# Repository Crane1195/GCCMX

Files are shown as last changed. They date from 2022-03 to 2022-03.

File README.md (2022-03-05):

# GCCMX
A digital controller PCB/chassis design.

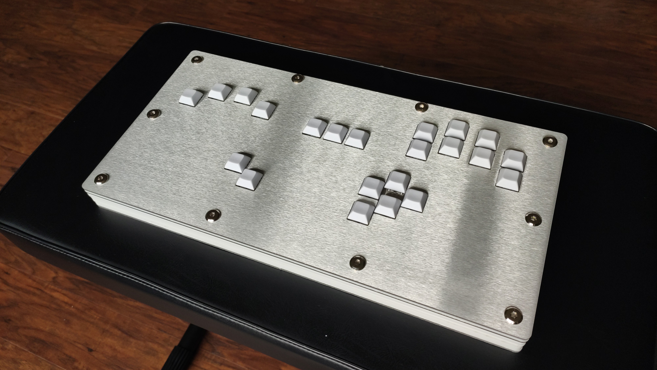
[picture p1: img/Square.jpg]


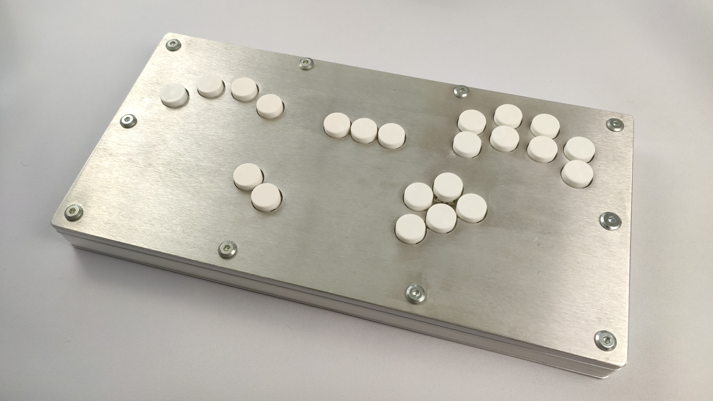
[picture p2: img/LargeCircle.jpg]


The PCB is originally designed to allow mounting a Model S and a Brook board, but you can also just solder wires to the through holes. The pin holes are labeled on the silk screen of the board.

## License
This project is licenced under the GNU GPL Version 3. [See the included LICENSE file for details](LICENSE).

## Support my work
I set up a donation link for people who appreciate my work and wish to donate. Donations are greatly appreciated, but are far from necessary:

https://www.paypal.com/donate/?hosted_button_id=NFDEML5FKR8N8

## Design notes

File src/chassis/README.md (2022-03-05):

## Switch Cover Layers

If you want to use Frame1/Gamerfinger sized keycaps (20.64mm), use a ~9mm GFCover layer.

If you want to use normal square keycaps, use a ~6mm SquareCover layer.

If you want to use small circular (sometimes called typewriter style) keycaps, you can either use a ~9mm GFCover layer to have the ability to swap to those later, or a ~6mm GFCover layer with a ~3mm SmallCover layer on top.

## Switch Plate

Get a ~1.5mm SwitchPlate layer in aluminum/steel/brass.

## Wall Layers

If you are using a GCCMX switch PCB + Model S logic PCB, use a 9mm GCCMXCover, and a 12mm ModelSCover.

If you want to use any other internals, with a Neutrik form factor feedthrough, get a 24mm GenericWallLayer.

If you want to use some other feedthrough, you can modify the GenericWallLayer file's cutout and order whatever thickenss panel fits your needs.

## Bottom Layer

Get whatever thickness Bottom panel that would be sturdy. I have done 3mm acrylic layers, and I imagine 1.5mm metal layers would be fine too.

## Model S USBC Cover

If you are using a Model S and have access to a 3D printer, this STL can be printed to cover the USBC cutout.

## Recommended US Laser Cutters

https://sendcutsend.com/ - Excellent metal cutting prices, free and fast production/shipping. Also has other materials nowadays. ACM is a really interesting/cheap material.

https://www.ponoko.com/ - Tons of material options, solid pricing, good bulk discounts, but they take quite a while to arrive.

https://www.pololu.com/product/749 - Fewer options than Ponoko, but still quite a lot. Similar pricing to Ponoko, but no bulk AFAIK. Ships faster than Ponoko.

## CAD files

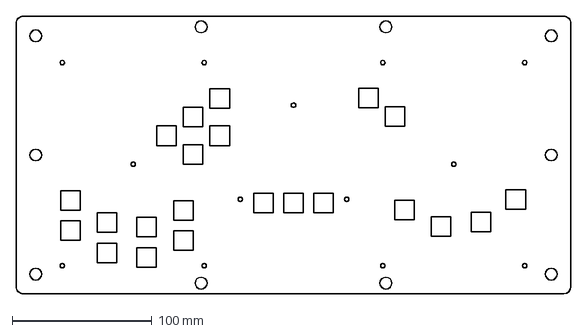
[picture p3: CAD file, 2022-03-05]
src/chassis/3_SwitchPlate.dxf
397.2 x 198.6 mm

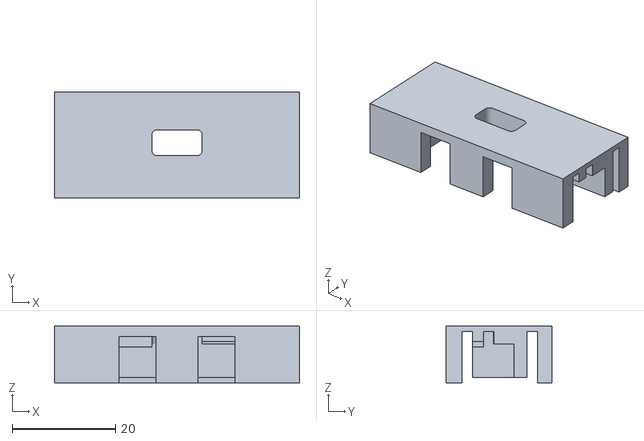
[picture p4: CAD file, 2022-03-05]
src/chassis/ModelS_USBC_Cover.stl
47.5 x 20.5 x 11.0

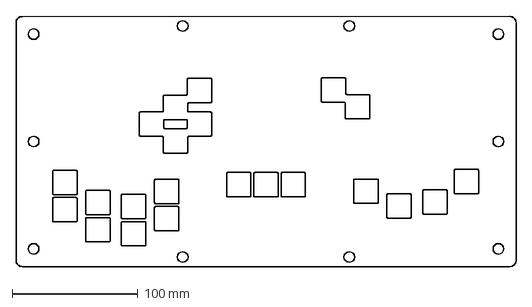
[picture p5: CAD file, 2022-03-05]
src/chassis/1_SquareCover.dxf
397.2 x 198.6 mm

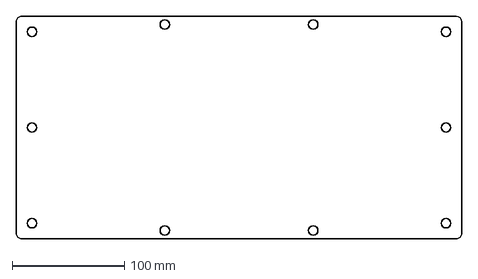
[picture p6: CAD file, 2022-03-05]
src/chassis/6_Bottom.dxf
397.2 x 198.6 mm

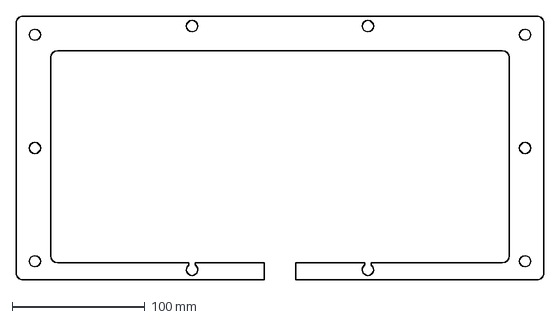
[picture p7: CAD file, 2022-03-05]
src/chassis/4+5_GenericWallLayer.dxf
397.2 x 198.6 mm

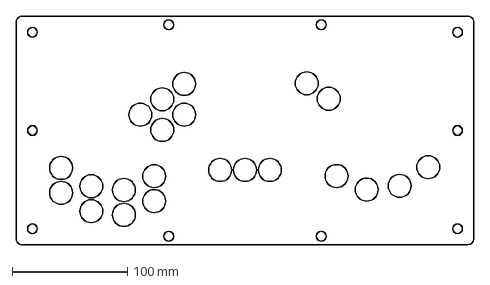
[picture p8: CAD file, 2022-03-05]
src/chassis/1_SmallCover.dxf
397.2 x 198.6 mm

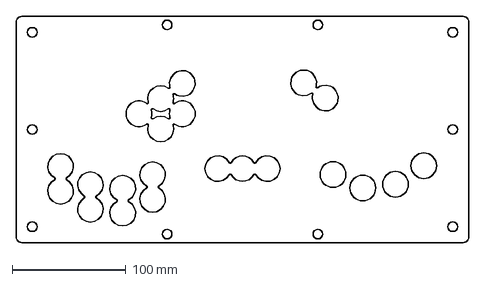
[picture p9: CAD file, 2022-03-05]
src/chassis/1_GFCover.dxf
397.2 x 198.6 mm

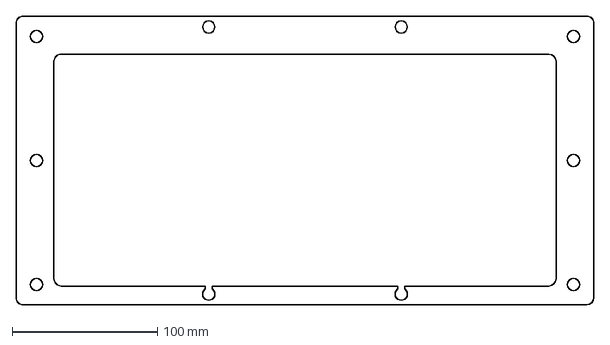
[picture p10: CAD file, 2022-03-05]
src/chassis/4_GCCMXCover.dxf
397.2 x 198.6 mm

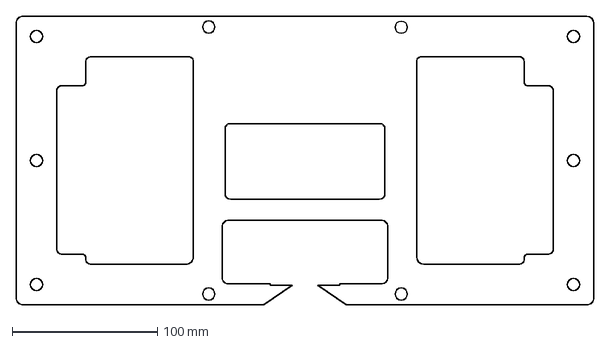
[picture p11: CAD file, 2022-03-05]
src/chassis/5_ModelSCover.dxf
397.2 x 198.6 mm

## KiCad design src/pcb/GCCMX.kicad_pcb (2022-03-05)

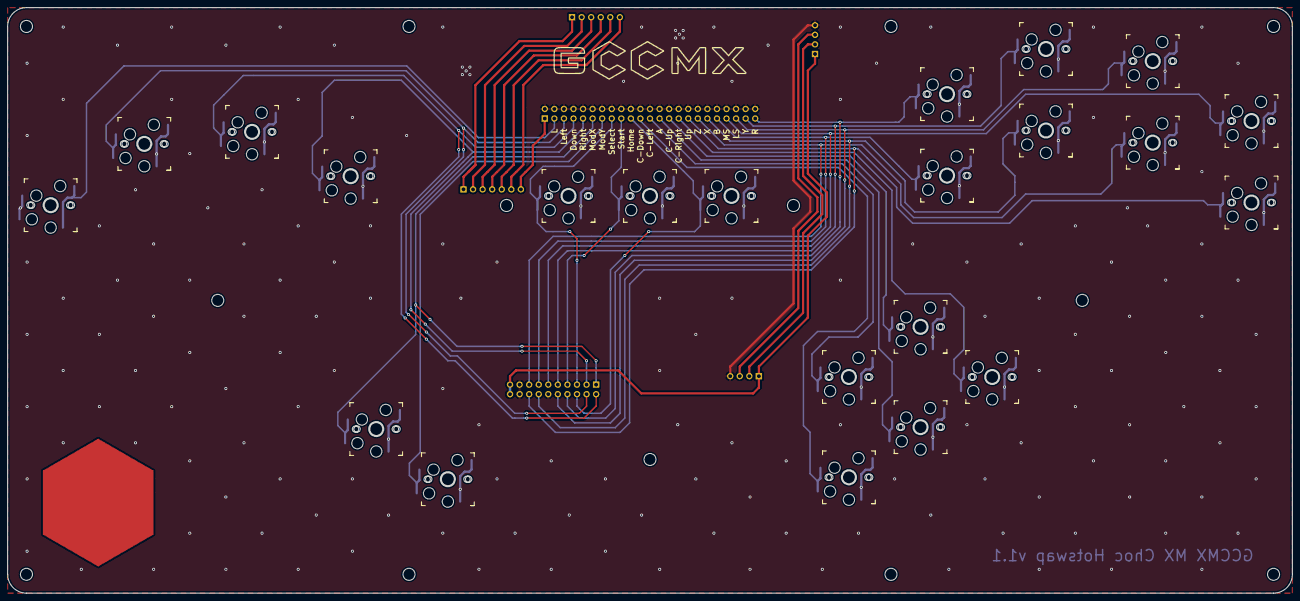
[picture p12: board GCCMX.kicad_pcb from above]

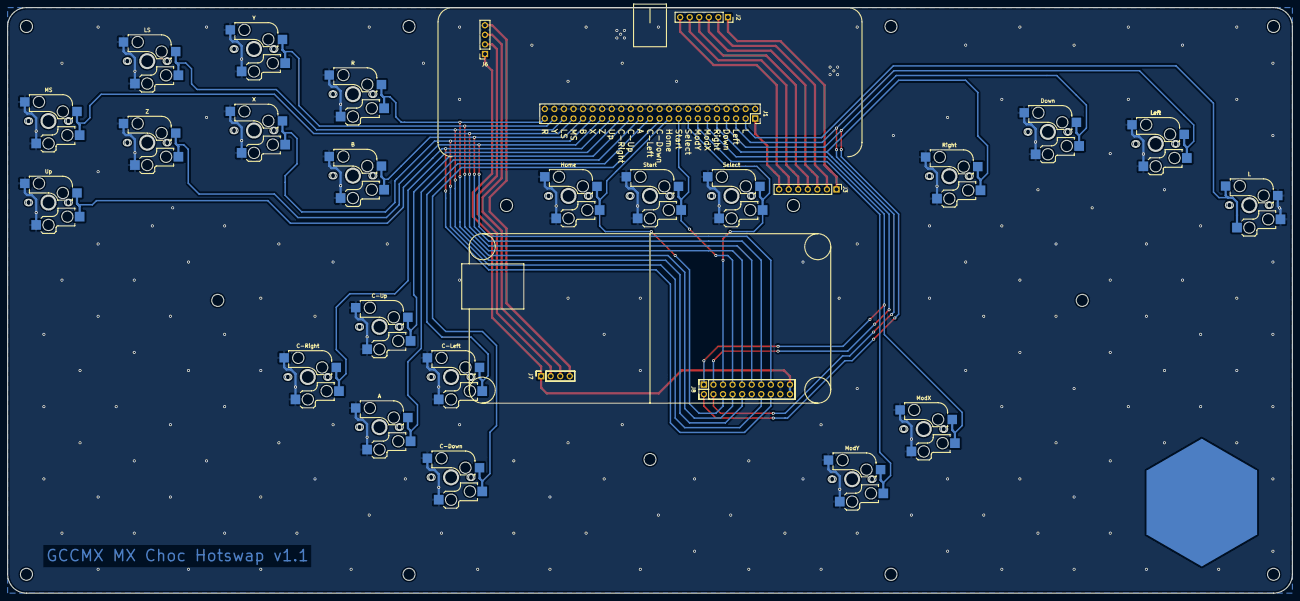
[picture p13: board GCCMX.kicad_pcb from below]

Board: 2 copper layers, 341.2 x 155.5 mm, 28 parts (6 on the bottom side), 33 nets.

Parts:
A: SW_SPST; Kailh_socket_MX+PG1350
B: SW_SPST; Kailh_socket_MX+PG1350
C-Down: SW_SPST; Kailh_socket_MX+PG1350
C-Left: SW_SPST; Kailh_socket_MX+PG1350
C-Right: SW_SPST; Kailh_socket_MX+PG1350
C-Up: SW_SPST; Kailh_socket_MX+PG1350
Down: SW_SPST; Kailh_socket_MX+PG1350
Home: SW_SPST; Kailh_socket_MX+PG1350
J1: Inputs Female; PinSocket_2x23_P2.54mm_Vertical
J2: Debug In; PinSocket_1x06_P2.54mm_Vertical
J3: Debug Out; PinHeader_1x07_P2.54mm_Vertical
J6: USB-IN; PinSocket_1x04_P2.54mm_Vertical
J7: USB-OUT; PinSocket_1x04_P2.54mm_Vertical
J8: Brook Out; PinSocket_2x10_P2.54mm_Vertical
L: SW_SPST; Kailh_socket_MX+PG1350
LS: SW_SPST; Kailh_socket_MX+PG1350
Left: SW_SPST; Kailh_socket_MX+PG1350
MS: SW_SPST; Kailh_socket_MX+PG1350
ModX: SW_SPST; Kailh_socket_MX+PG1350
ModY: SW_SPST; Kailh_socket_MX+PG1350
R: SW_SPST; Kailh_socket_MX+PG1350
Right: SW_SPST; Kailh_socket_MX+PG1350
Select: SW_SPST; Kailh_socket_MX+PG1350
Start: SW_SPST; Kailh_socket_MX+PG1350
Up: SW_SPST; Kailh_socket_MX+PG1350
X: SW_SPST; Kailh_socket_MX+PG1350
Y: SW_SPST; Kailh_socket_MX+PG1350
Z: SW_SPST; Kailh_socket_MX+PG1350

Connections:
/A: A.2, J1.25
/B: B.2, J1.37, J8.13
/C-D: C-Down.2, J1.21
/C-L: C-Left.2, J1.23
/C-R: C-Right.2, J1.29
/C-U: C-Up.2, J1.27
/Down: Down.2, J1.7, J8.2
/Home: Home.2, J1.19, J8.6
/L: J1.3, L.1
/LS: J1.41, J8.10, LS.2
/Left: J1.5, J8.4, Left.2
/MS: J1.39, J8.11, MS.2
/ModX: J1.11, J8.1, ModX.2
/ModY: J1.13, ModY.2
/R: J1.45, J8.8, R.2
/Right: J1.9, J8.3, Right.2
/Select: J1.15, J8.5, Select.2
/Start: J1.17, J8.7, Start.2
/TXLED: J1.1, J3.7
/Up: J1.31, J8.16, Up.2
/X: J1.35, J8.14, X.2
/Y: J1.43, J8.9, Y.2
/Z: J1.33, J8.15, Z.2
GND: A.1, B.1, C-Down.1, C-Left.1, C-Right.1, C-Up.1, Down.1, Home.1, J1.2, J1.4, J1.6, J1.8, J1.10, J1.12, J1.14, J1.16, J1.18, J1.20, J1.22, J1.24, J1.26, J1.28, J1.30, J1.32, J1.34, J1.36, J1.38, J1.40, J1.42, J1.44, J1.46, J6.4, J7.4, J8.12, J8.17, J8.18, L.2, LS.1, Left.1, MS.1, ModX.1, ModY.1, R.1, Right.1, Select.1, Start.1, Up.1, X.1, Y.1, Z.1
unnamed: J2.1, J3.1
unnamed: J2.2, J3.2
unnamed: J2.3, J3.3
unnamed: J2.4, J3.4
unnamed: J2.5, J3.5
unnamed: J2.6, J3.6
unnamed: J6.2, J7.2
unnamed: J6.3, J7.3
VBUS: J6.1, J7.1, J8.19, J8.20
